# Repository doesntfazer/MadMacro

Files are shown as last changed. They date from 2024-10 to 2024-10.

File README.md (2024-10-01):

# MadMacro

 The MadMacro macro pad inspired by the game Deadlock. It has extra keys by the pinky for spells, abilities, and whatever else you would want to do with it.
 461258581_537994958962840_3594091435588228530_n
461801669_423427187437874_2293081744220091952_n

# Firmware
 This keyboard runs on Vial QMK. Firmware is in the [Keyboard Dweebs Firmware repository.](https://github.com/doesntfazer/Keyboard-Dweebs-Firmware-repository/tree/main/VIAL-QMK/madmacro) Just drag and drop the UF2 file into the drive in bootloader mode.

# Supplies
| Amount | Supplies |
| --- | --- |
|1x|PCB|
|1x|[Super Mini RP2040](https://www.aliexpress.us/item/3256805724197386.html?gatewayAdapt=glo2usa4itemAdapt) (Keep in mind that the RP2040 zero is compatible as well But it will not sit flush)|
|  1x | [WS2712B 5050 RGB (Optional)](https://www.aliexpress.us/item/3256805981215355.html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)  |
| 1x | [SN74LVC1T45 Shift register.](https://www.lcsc.com/product-detail/74-Series_TI_SN74LVC1T45QDCKRQ1_SN74LVC1T45QDCKRQ1_C139353.html) (part #C139353 on JLCPCB) (only needed if using RGB) |
| 33x | [Kailh hot swap sockets.](https://www.aliexpress.us/item/3256806866334888.html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) |
|33x|[1n4148w SOD-123 SMD diodes](https://www.aliexpress.us/item/2251832762203586.html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) |
|33x|Cherry MX or compatible switches|
|4x|1.25u keycaps|
|4x|1.5u keycaps|
|25x|1u keycaps|
|1x|Plate (3d printable in the 3d Models folder in this repo)|
|1x|Bottom (3d printable in the 3d Models folder in this repo)|
|1x|Wrist rest (optional)(3d printable in the 3d Models folder in this repo)|
|4x|6x2mm magnets (Optional if using wrist rest)|
|5x|M2 screws (At least 8mm long)|

# Ordering
Send the Gerber zip in the production folder to PCBWay or JLCPCB. (There are files to have it assembled at the factory. That is up to you)

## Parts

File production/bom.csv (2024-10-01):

Designator | Footprint | Quantity | Value | LCSC Part #
D1, D10, D11, D12, D13, D14, D15, D16, D17, D18, D19, D2, D20, D21, D22, D23, D24, D25, D26, D27, D28, D29, D3, D30, D31, D32, D33, D4, D5, D6, D7, D8, D9 | D_SOD-123 | 33 | 1N4148W
D34 | LED_WS2812B_PLCC4_5.0x5.0mm_P3.2mm | 1 | WS2812B
SW1, SW10, SW11, SW12, SW13, SW15, SW16, SW17, SW18, SW19, SW2, SW20, SW22, SW23, SW24, SW25, SW26, SW27, SW29, SW3, SW4, SW5, SW6, SW8, SW9 | SW_Hotswap_Kailh_MX_1.00u | 25 | SW_PUSH
SW14, SW21, SW28, SW7 | SW_Hotswap_Kailh_MX_1.25u | 4 | SW_PUSH
SW30, SW31, SW32, SW33 | SW_Hotswap_Kailh_MX_1.50u_90deg | 4 | SW_PUSH
U1 | rp2040-zero-tht-nocut-largerpads | 1 | rp2040-zero
U2 | SOT-363_SC-70-6 | 1 | SN74LVC1T45DCK | C139353

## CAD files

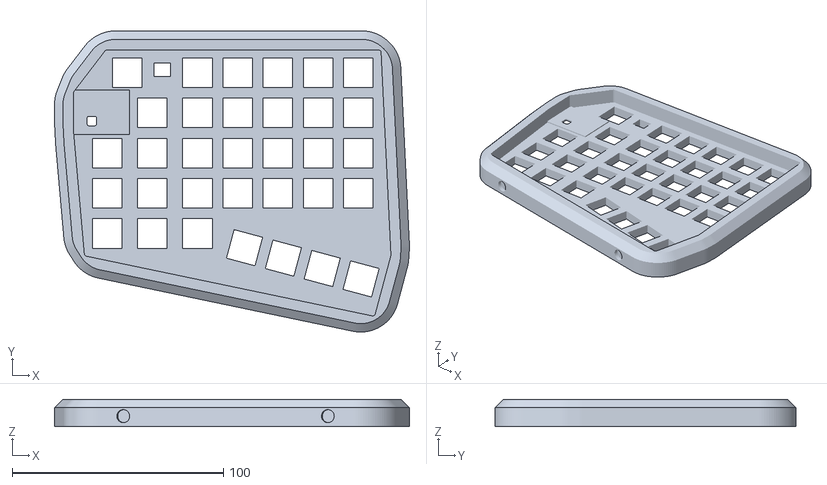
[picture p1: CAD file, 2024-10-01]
3d Models/Plate-Magnetic.stl
168.2 x 142.7 x 13.0

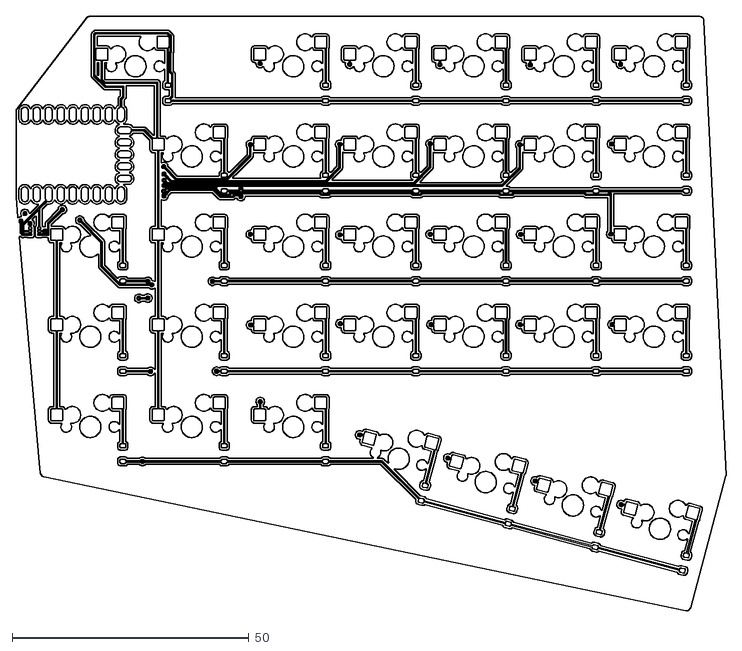
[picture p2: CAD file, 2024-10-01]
DXF/MadMacro-B_Cu.dxf
150.0 x 125.6

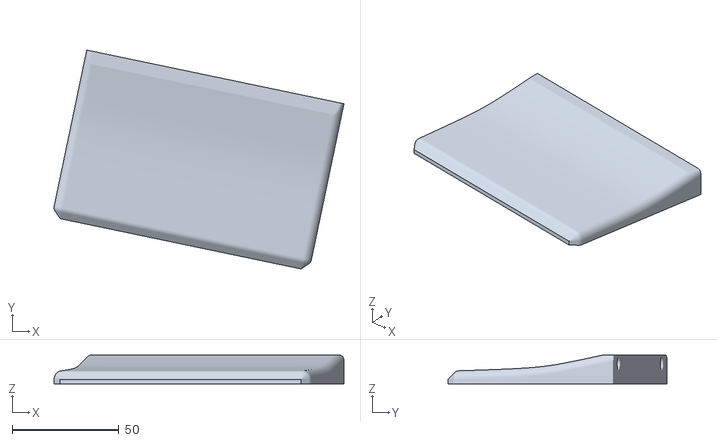
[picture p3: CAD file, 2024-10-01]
3d Models/Wrist rest.stl
136.1 x 102.7 x 13.5

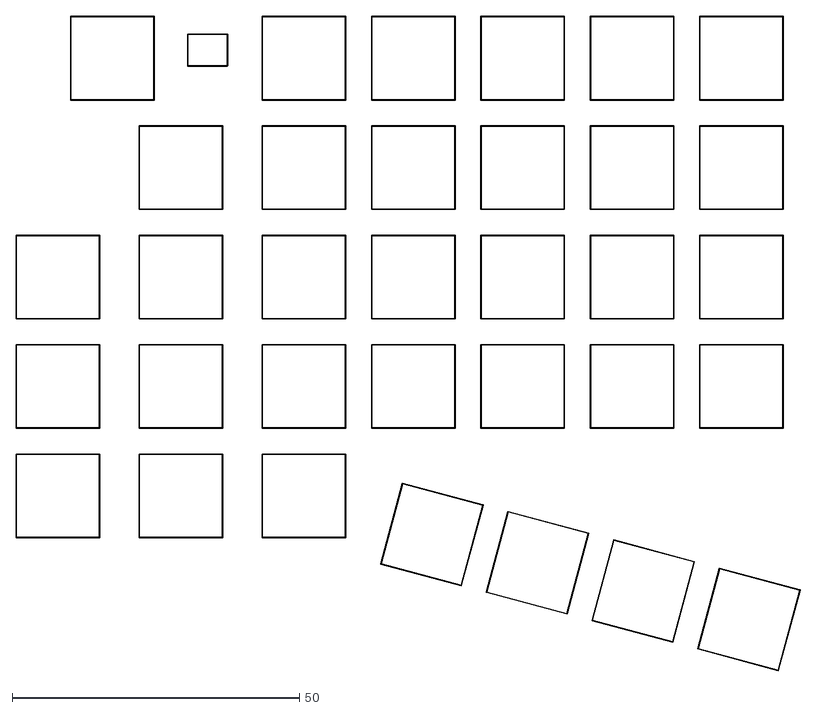
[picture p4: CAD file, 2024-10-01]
DXF/MadMacro-F_Courtyard.dxf
136.5 x 113.9

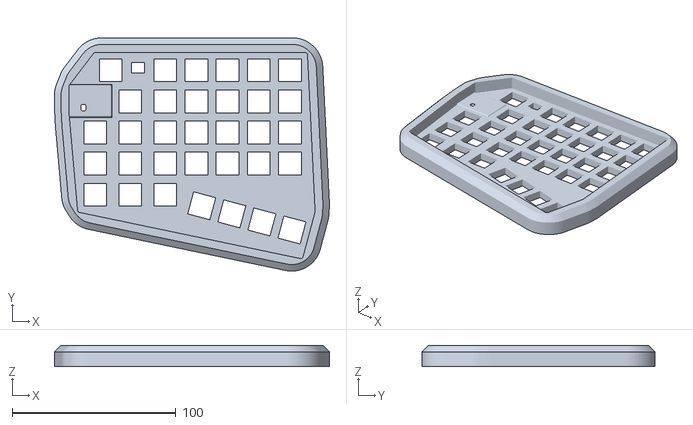
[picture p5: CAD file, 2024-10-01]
3d Models/Plate.stl
168.2 x 142.7 x 13.0

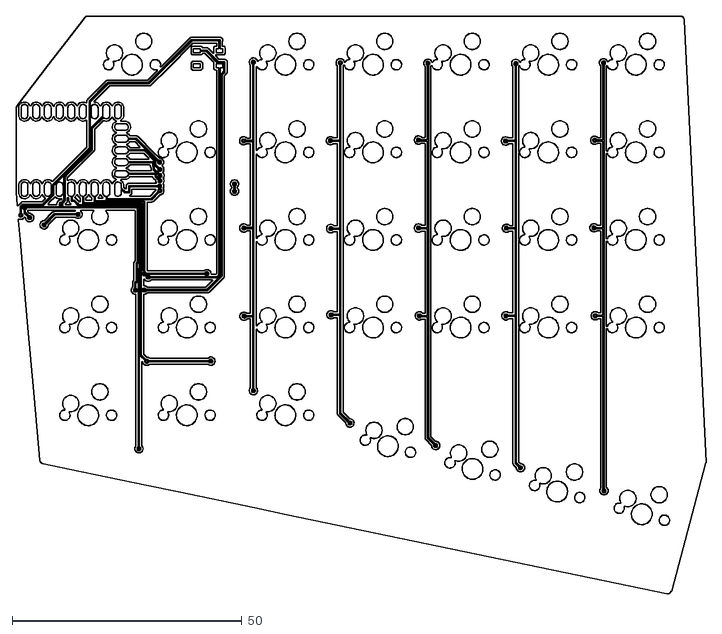
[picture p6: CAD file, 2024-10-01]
DXF/MadMacro-F_Cu.dxf
150.0 x 125.6

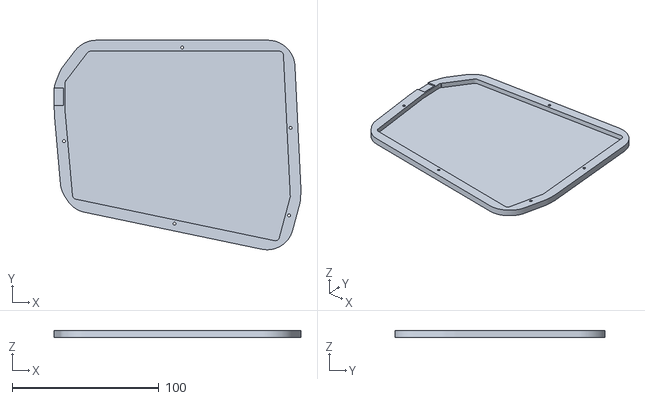
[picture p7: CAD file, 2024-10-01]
3d Models/Bottom.stl
168.2 x 142.7 x 4.50

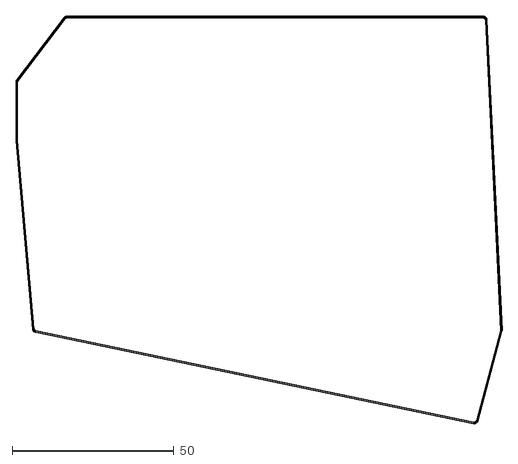
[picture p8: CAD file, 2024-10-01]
DXF/MadMacro-Edge_Cuts.dxf
150.4 x 126.0

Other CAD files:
DXF/MadMacro-B_Mask.dxf
DXF/MadMacro-B_Paste.dxf
DXF/MadMacro-B_Silkscreen.dxf
DXF/MadMacro-F_Mask.dxf
DXF/MadMacro-F_Paste.dxf
DXF/MadMacro-F_Silkscreen.dxf

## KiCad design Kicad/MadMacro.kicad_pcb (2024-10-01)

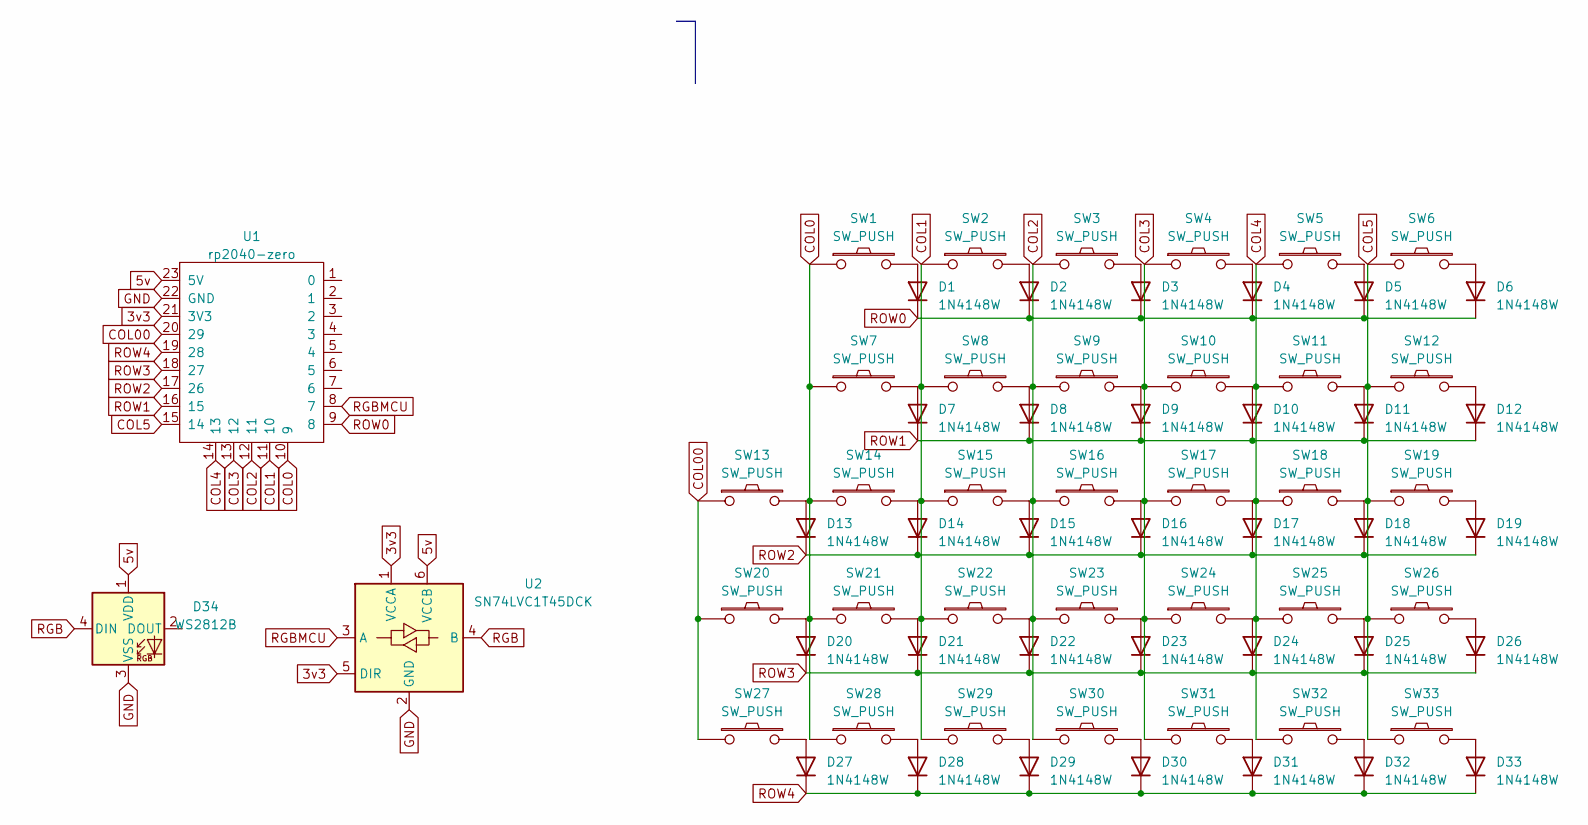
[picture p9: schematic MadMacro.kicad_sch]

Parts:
D1, D2, D3, D4, D5, D6, D7, D8, D9, D10, D11, D12, D13, D14, D15, D16, D17, D18, D19, D20, D21, D22, D23, D24, D25, D26, D27, D28, D29, D30, D31, D32, D33: 1N4148W; D_SOD-123
D34: WS2812B; LED_WS2812B_PLCC4_5.0x5.0mm_P3.2mm
SW1, SW2, SW3, SW4, SW5, SW6, SW8, SW9, SW10, SW11, SW12, SW13, SW15, SW16, SW17, SW18, SW19, SW20, SW22, SW23, SW24, SW25, SW26, SW27, SW29: SW_PUSH; SW_Hotswap_Kailh_MX_1.00u
SW7, SW14, SW21, SW28: SW_PUSH; SW_Hotswap_Kailh_MX_1.25u
SW30, SW31, SW32, SW33: SW_PUSH; SW_Hotswap_Kailh_MX_1.50u_90deg
U1: rp2040-zero; rp2040-zero-tht-nocut-largerpads
U2: SN74LVC1T45DCK; SOT-363_SC-70-6; LCSC C139353

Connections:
3v3: U1.21 (3V3), U2.1 (VCCA), U2.5 (DIR)
5v: D34.1 (VDD), U1.23 (5V), U2.6 (VCCB)
COL0: SW1.1, SW7.1, SW14.1, SW21.1, SW28.1, U1.10 (9)
COL00: SW13.1, SW20.1, SW27.1, U1.20 (29)
COL1: SW2.1, SW8.1, SW15.1, SW22.1, SW29.1, U1.11 (10)
COL2: SW3.1, SW9.1, SW16.1, SW23.1, SW30.1, U1.12 (11)
COL3: SW4.1, SW10.1, SW17.1, SW24.1, SW31.1, U1.13 (12)
COL4: SW5.1, SW11.1, SW18.1, SW25.1, SW32.1, U1.14 (13)
COL5: SW6.1, SW12.1, SW19.1, SW26.1, SW33.1, U1.15 (14)
GND: D34.3 (VSS), U1.22 (GND), U2.2 (GND)
unnamed: D1.2 (A), SW1.2
unnamed: D2.2 (A), SW2.2
unnamed: D3.2 (A), SW3.2
unnamed: D4.2 (A), SW4.2
unnamed: D5.2 (A), SW5.2
unnamed: D6.2 (A), SW6.2
unnamed: D7.2 (A), SW7.2
unnamed: D8.2 (A), SW8.2
unnamed: D9.2 (A), SW9.2
unnamed: D10.2 (A), SW10.2
unnamed: D11.2 (A), SW11.2
unnamed: D12.2 (A), SW12.2
unnamed: D13.2 (A), SW13.2
unnamed: D14.2 (A), SW14.2
unnamed: D15.2 (A), SW15.2
unnamed: D16.2 (A), SW16.2
unnamed: D17.2 (A), SW17.2
unnamed: D18.2 (A), SW18.2
unnamed: D19.2 (A), SW19.2
unnamed: D20.2 (A), SW20.2
unnamed: D21.2 (A), SW21.2
unnamed: D22.2 (A), SW22.2
unnamed: D23.2 (A), SW23.2
unnamed: D24.2 (A), SW24.2
unnamed: D25.2 (A), SW25.2
unnamed: D26.2 (A), SW26.2
unnamed: D27.2 (A), SW27.2
unnamed: D28.2 (A), SW28.2
unnamed: D29.2 (A), SW29.2
unnamed: D30.2 (A), SW30.2
unnamed: D31.2 (A), SW31.2
unnamed: D32.2 (A), SW32.2
unnamed: D33.2 (A), SW33.2
RGB: D34.4 (DIN), U2.4 (B)
RGBMCU: U1.8 (7), U2.3 (A)
ROW0: D1.1 (K), D2.1 (K), D3.1 (K), D4.1 (K), D5.1 (K), D6.1 (K), U1.9 (8)
ROW1: D7.1 (K), D8.1 (K), D9.1 (K), D10.1 (K), D11.1 (K), D12.1 (K), U1.16 (15)
ROW2: D13.1 (K), D14.1 (K), D15.1 (K), D16.1 (K), D17.1 (K), D18.1 (K), D19.1 (K), U1.17 (26)
ROW3: D20.1 (K), D21.1 (K), D22.1 (K), D23.1 (K), D24.1 (K), D25.1 (K), D26.1 (K), U1.18 (27)
ROW4: D27.1 (K), D28.1 (K), D29.1 (K), D30.1 (K), D31.1 (K), D32.1 (K), D33.1 (K), U1.19 (28)

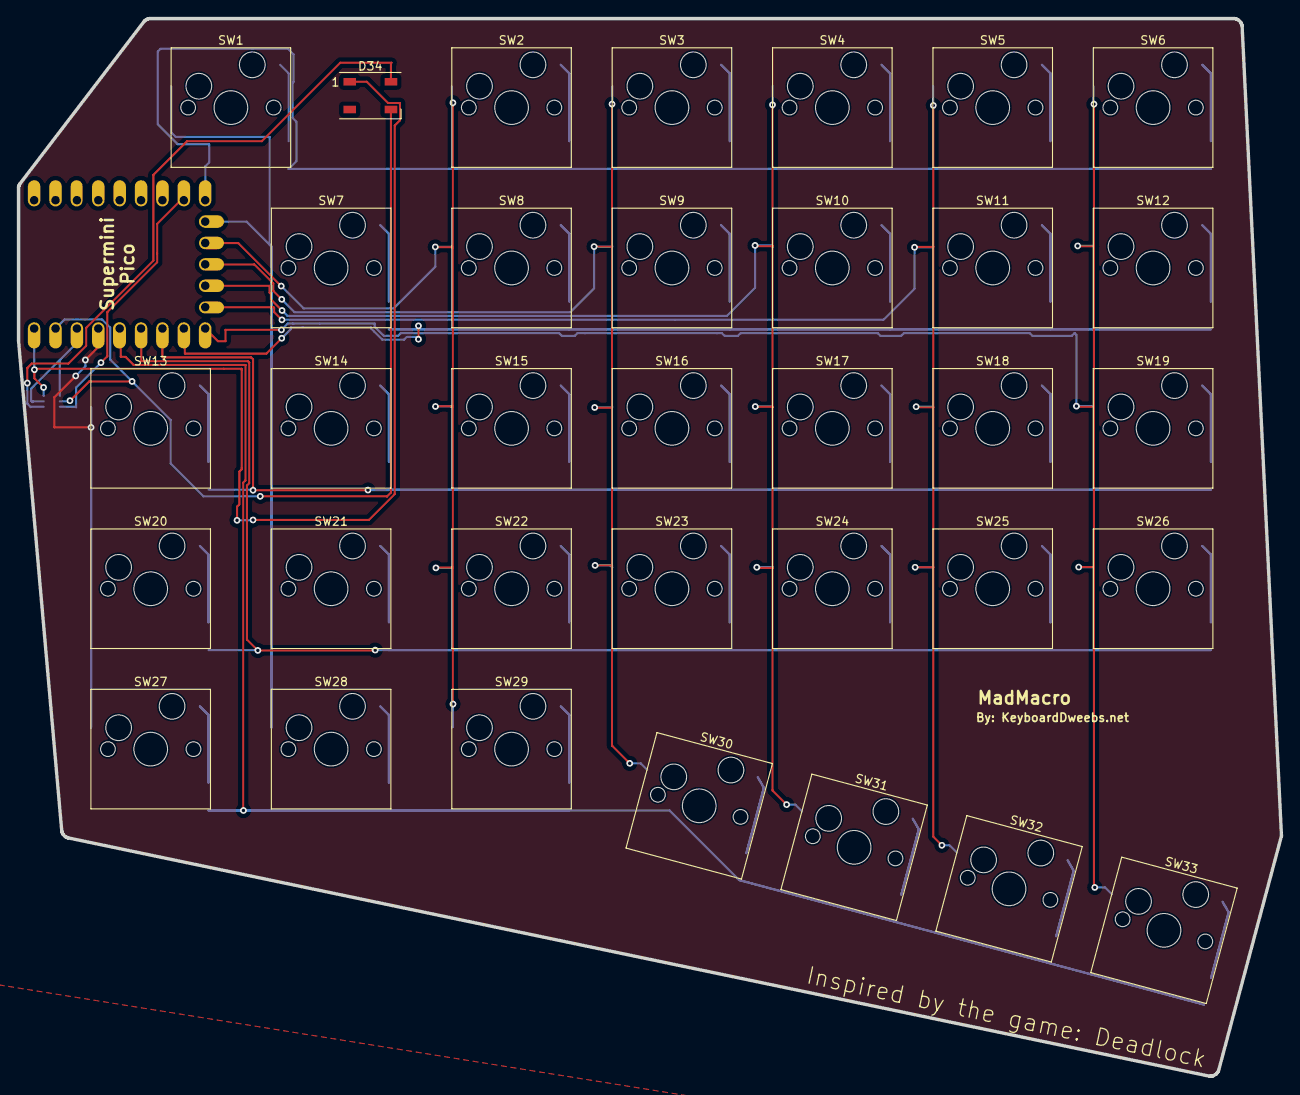
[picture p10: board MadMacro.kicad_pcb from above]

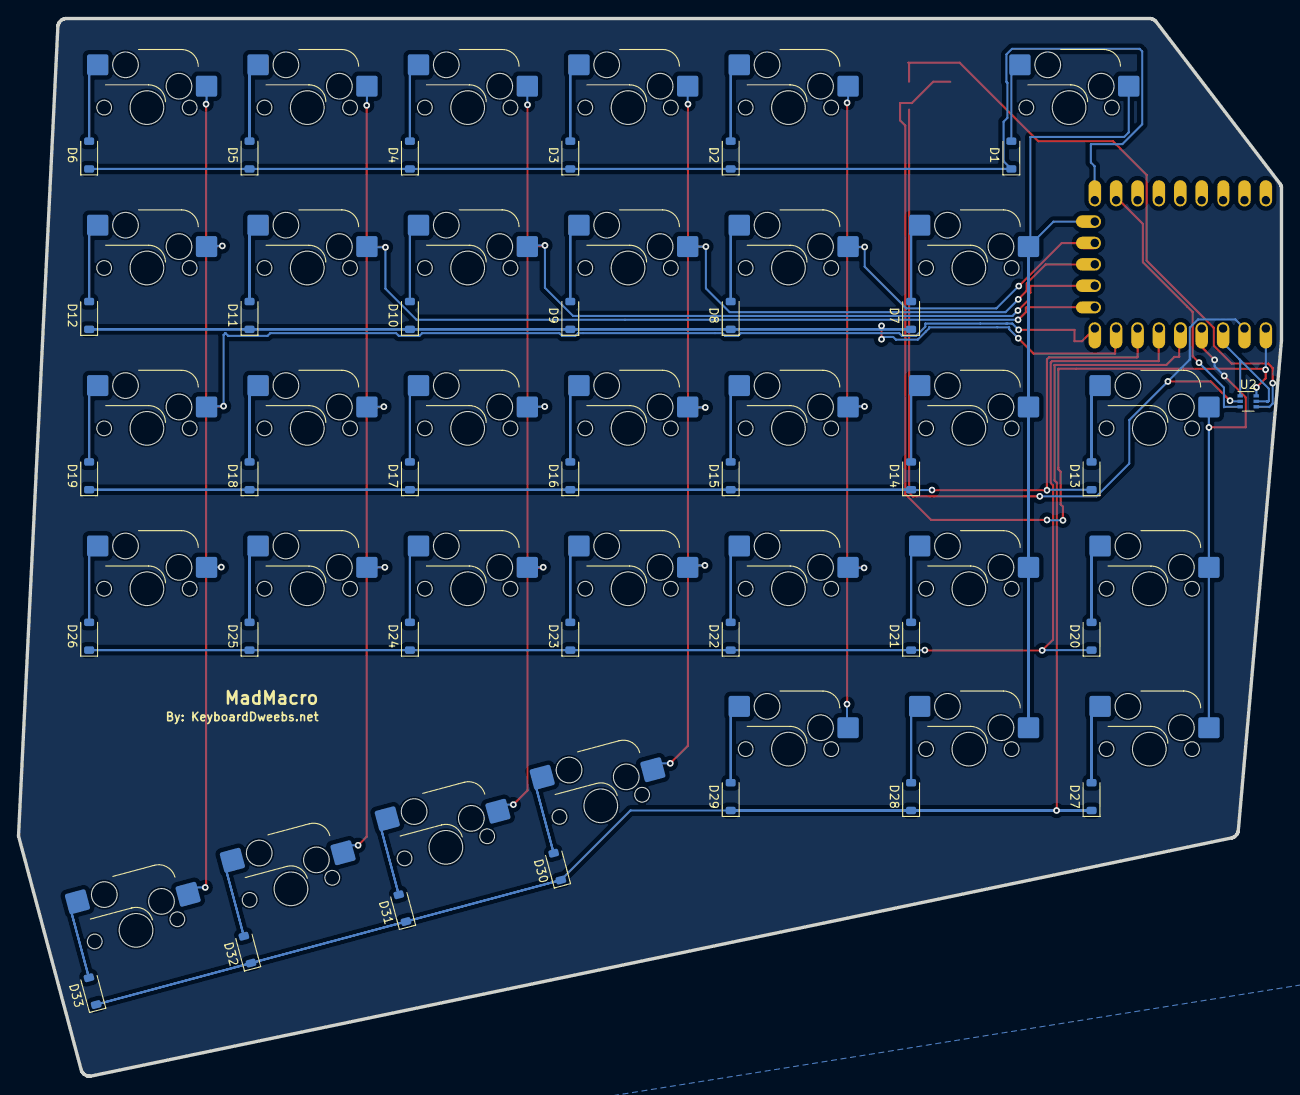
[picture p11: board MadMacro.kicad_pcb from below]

Board: 2 copper layers, 150.0 x 125.6 mm, 69 parts (34 on the bottom side), 50 nets.
